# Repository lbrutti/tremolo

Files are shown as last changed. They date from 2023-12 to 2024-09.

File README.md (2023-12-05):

# Tremolo
 
In this project, I made a tremolo modulation pedal with wave altering feature for a guitar using an Arduino and an optocoupler.
<br/><br/>
Required components:
| Component | Quantity| 
| --- |-----:|
| Arduino Nano (Mini USB) | 1 |
| 10K Potentiometers | 3 |
| 250K Potentiometer | 1 |
| 1/4 InchMono Input Jack | 2 |
| PC817B Optocoupler | 1 |
| LED | 1 |
| PLA (If you want to print your case) | 1 |

The following is the wiring required from the Arduino Pins:
10 to LED;
11 to Optocupler;
A0 to 10K Potentiometer [peek bias (Sawtooth wave)];
A1 to 10K Potentiometer [waveform];
A2 to 10K Potentiometer [rate]
then one wire from the Jacks can be corrected directly to the matching connector on the other jack and the other can be connected through the Optocoupler and the 250K Potentiometer.

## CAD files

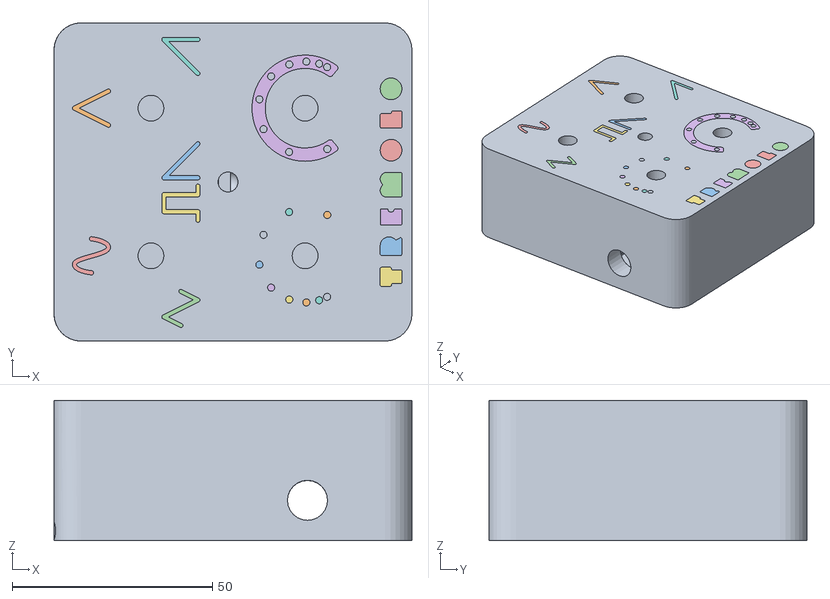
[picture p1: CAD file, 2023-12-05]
Case.obj
89.3 x 79.4 x 35.0

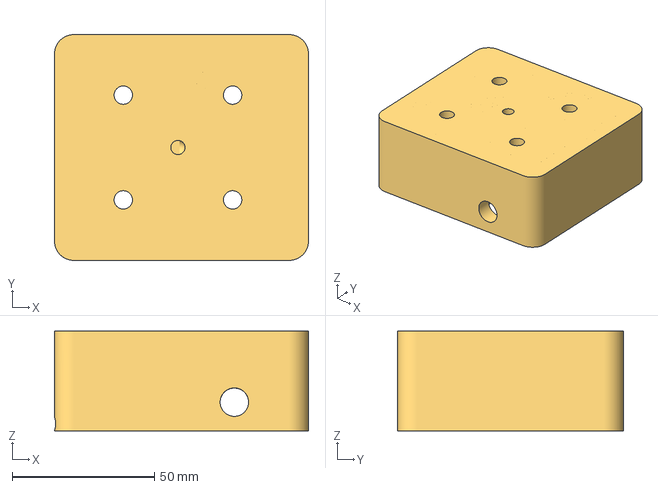
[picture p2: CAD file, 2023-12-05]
Case_Part_1.3mf
89.3 x 79.4 x 35.0 mm

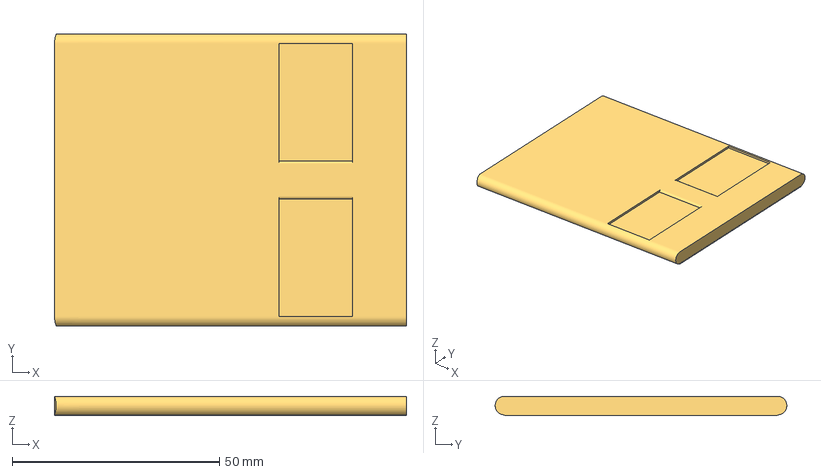
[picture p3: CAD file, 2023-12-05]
Case_Part_2.3mf
85.0 x 70.4 x 4.70 mm

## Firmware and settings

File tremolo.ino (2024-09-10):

/**
 * The following is the wiring required from the Arduino Pins: 
 *  10 to LED; 
 *  11 to Optocupler; 
 *  A0 to 10K Potentiometer [peek bias (Sawtooth wave)]; 
 *  A1 to 10K Potentiometer [waveform]; 
 *  A2 to 10K Potentiometer [rate] 
 *  then one wire from the Jacks can be corrected directly to the 
 *  matching connector on the other jack and the other can be connected 
 *  through the Optocoupler and the 250K Potentiometer.
 */

void setup() {
  pinMode(10, OUTPUT);//to LED
  pinMode(11, OUTPUT);//to Optocupler
  pinMode(A0, INPUT);//peek bias
  pinMode(A1, INPUT);//waveform
  pinMode(A2, INPUT);//rate
  //Serial.begin(9600);
}

double delayTime = 2;
double rise_bias = 14;
double fall_bias = 14;
 
void loop() {
  for (double i = 0; i <= 255; i+= rise_bias) { 
    checkInterupts();
    delay(delayTime);   
    double waveform = toWaveForm(i);
    analogWrite(10, waveform);
    analogWrite(11, waveform);
    
       //Serial.print(waveform);
       //Serial.print(",");
       //Serial.print(delayTime);
       //Serial.print(",");
       //Serial.print(analogRead(A0));
       //Serial.print(",");
       //Serial.print(rise_bias);
       //Serial.print(",");
       //Serial.println(fall_bias);
  }
  for (double i = 255; i >= 0; i-= fall_bias) {
    checkInterupts() ;
    delay(delayTime);    
    double waveform = toWaveForm(i);
    analogWrite(10,waveform);
    analogWrite(11, waveform);

      //Serial.print(waveform);
       //Serial.print(",");
       //Serial.print(delayTime);
       //Serial.print(",");
       //Serial.print(analogRead(A0));
       //Serial.print(",");
       //Serial.print(rise_bias);
       //Serial.print(",");
       //Serial.println(fall_bias);
  }
}

double toWaveForm(double tryangle_wave) {
  //set shape shifting multiplier 0-3
  double wave_form_multiplier = ((0.0000019073486 * pow((analogRead(A1)-20), 2)) + (0.0009765625 * (analogRead(A1)-20)));//20 is potensiometer offset!
   //Serial.print(wave_form_multiplier);
   //Serial.print(",");

  float sine_wave = ((((cos((tryangle_wave/255)*3.141592653589+3.141592653589))/2)+0.5)*255);
  if (wave_form_multiplier <= 1){
    float difference = tryangle_wave - sine_wave;
    difference = difference * wave_form_multiplier;
    return (tryangle_wave - difference);
  }else{//wave clipping
    double new_sine_wave = (((sine_wave) * wave_form_multiplier));
    new_sine_wave = new_sine_wave - ((wave_form_multiplier - 1) * 127.5);
    if(new_sine_wave > 255){
      new_sine_wave = 255;
    }else if(new_sine_wave < 0){
      new_sine_wave = 0;
    }
    return new_sine_wave;
  }
}

void checkInterupts(){
  //set delay time
  delayTime = (((double)analogRead(A2)-40)/20);//40 is potensiometer offset
  if(delayTime<0){
    delayTime = 0;
  }


  //set peek bias
  rise_bias = (((analogRead(A0)-30)/40.96)+2.5);//0-28//1.5-26.5 //30 is potensiometer offset!
  if(rise_bias < 0.01){
    rise_bias = 0.01;
  }
  fall_bias = 30 - rise_bias; 

}

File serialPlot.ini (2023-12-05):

[MainWindow]
size=@Size(1663 724)
pos=@Point(103 143)
activePanel=Plot
hidePanels=false
maximized=false
state=@ByteArray(\0\0\0\xff\0\0\0\0\xfd\0\0\0\0\0\0\x6\x7f\0\0\x2y\0\0\0\x4\0\0\0\x4\0\0\0\b\0\0\0\b\xfc\0\0\0\x1\0\0\0\x2\0\0\0\x3\0\0\0\f\0t\0\x62\0P\0l\0o\0t\x1\0\0\0\0\0\0\0\x92\0\0\0\0\0\0\0\0\0\0\0\x1a\0t\0\x62\0P\0o\0r\0t\0\x43\0o\0n\0t\0r\0o\0l\x1\0\0\0\x92\0\0\x1\x8e\0\0\0\0\0\0\0\0\0\0\0\x10\0t\0\x62\0R\0\x65\0\x63\0o\0r\0\x64\x1\0\0\x2 \xff\xff\xff\xff\0\0\0\0\0\0\0\0)

[Port]
selectedPort=COM9
baudRate=9600
parity=none
dataBits=8
stopBits=1
flowControl=none

[DataFormat]
format=ascii

[DataFormat_Binary]
numOfChannels=3
numberFormat=uint8
endianness=little

[DataFormat_ASCII]
numOfChannels=auto
delimiter=other
customDelimiter=","
filterMode=disabled
filterPrefix=","

[DataFormat_CustomFrame]
numOfChannels=1
numberFormat=uint8
endianness=little
frameStart=AA BB
fixedSize=false
frameSize=1
checksum=false
debugMode=false

[Channels]
channel\1\name=Wave Form Multiplier
channel\1\color=@Variant(\0\0\0\x43\x1\xff\xff\xaa\xaa\xff\xff\xff\xff\0\0)
channel\1\visible=true
channel\1\gain=100
channel\1\gainEnabled=true
channel\1\offset=0
channel\1\offsetEnabled=false
channel\2\name=Output Wave
channel\2\color=@Variant(\0\0\0\x43\x1\xff\xff\xaa\xaa\xaa\xaa\xff\xff\0\0)
channel\2\visible=true
channel\2\gain=1
channel\2\gainEnabled=true
channel\2\offset=0
channel\2\offsetEnabled=false
channel\3\name=Rate
channel\3\color=@Variant(\0\0\0\x43\x1\xff\xffUU\xff\xff\x7f\x7f\0\0)
channel\3\visible=true
channel\3\gain=1
channel\3\gainEnabled=true
channel\3\offset=0
channel\3\offsetEnabled=false
channel\4\name=Peek Bias
channel\size=6
channel\4\color=@Variant(\0\0\0\x43\x1\xff\xff\xff\xff\xaa\xaa\xff\xff\0\0)
channel\4\visible=true
channel\4\gain=0.1
channel\4\gainEnabled=true
channel\4\offset=0
channel\4\offsetEnabled=false
channel\5\name=Rise
channel\5\color=@Variant(\0\0\0\x43\x1\xff\xff\xff\xffUU\0\0\0\0)
channel\5\visible=true
channel\5\gain=10
channel\5\gainEnabled=true
channel\5\offset=0
channel\5\offsetEnabled=false
channel\6\name=Fall
channel\6\color=@Variant(\0\0\0\x43\x1\xff\xffjj\x82\x82ll\0\0)
channel\6\visible=true
channel\6\gain=10
channel\6\gainEnabled=true
channel\6\offset=0
channel\6\offsetEnabled=false

[Plot]
numOfSamples=1500
plotWidth=500
indexAsX=true
xMax=500
xMin=0
autoScale=true
yMax=300
yMin=-30
darkBackground=true
grid=true
minorGrid=false
legend=true
multiPlot=false
symbols=auto
numLines=1
decimals=2

[Commands]
command\1\name=Command 1
command\1\type=ascii
command\1\data=
command\size=1

[Record]
autoIncrement=true
recordPaused=true
stopOnClose=true
header=true
disableBuffering=false
separator=","
decimals=6
timestamp=false
timestampFormat=seconds

[UpdateCheck]
periodicCheck=true
lastCheck=2023-11-28
